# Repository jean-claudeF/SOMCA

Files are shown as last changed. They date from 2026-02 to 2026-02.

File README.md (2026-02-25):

# SOMCA
Switch Off load &amp; Measure Capacity of batteries

Controlled battery discharge and capacity measurement

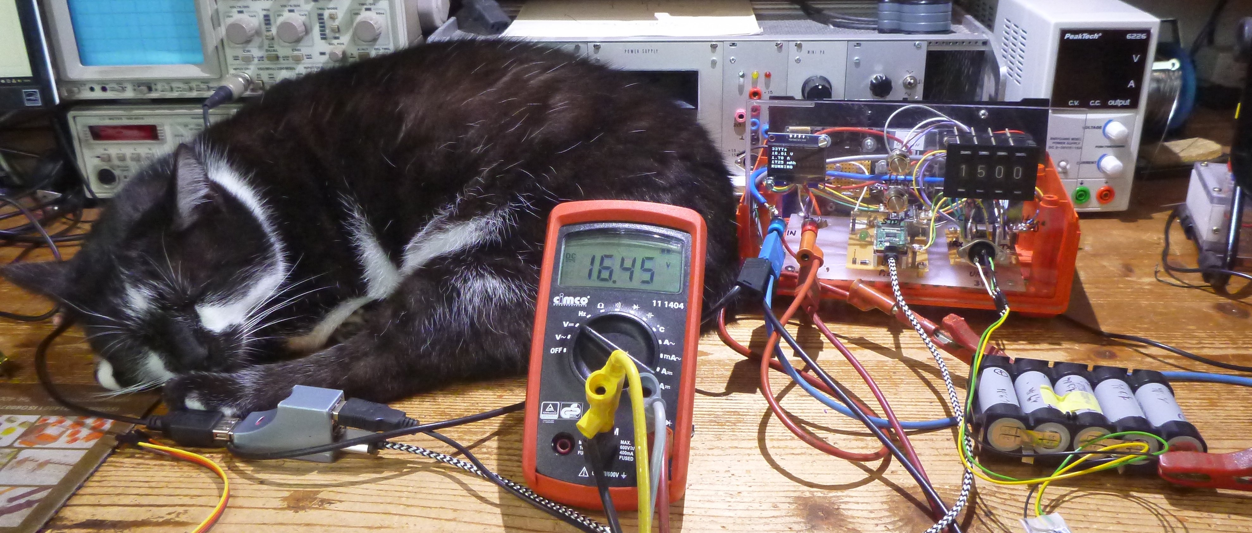
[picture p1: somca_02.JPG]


This picture shows (from left to right) my assistant Billy, a voltmeter showing battery voltage, SOMCA the device that switches off the load when voltage drops below a threshold adjustable with the BCD switches on the right of the frontplate. The battery on the right in front is connected to the input, a power resistor load is lying on the floor and is not visible here.

SOMCA has the following purposes:

1. switch off the load when voltage drops under the threshold, to prevent battery damage
2. measure voltage and current over time
3. from these calculate charge in As and Ah, and energy in Wh
4. store these values for later analysis

In contrast to my other project https://github.com/jean-claudeF/LiIonCapacityMeter that does about the same for single 18650 cells, this is for use with "bigger" batteries like those for electric bicycles or modules from electric cars, like those that I use in my solar energy project.

Limitations:
- voltage must be >= ca. 4V, otherwise the MOSFET will not correctly switch on
- currents up to 10A should be no problem, I have not tested with more

## Hardware

### Switching unit

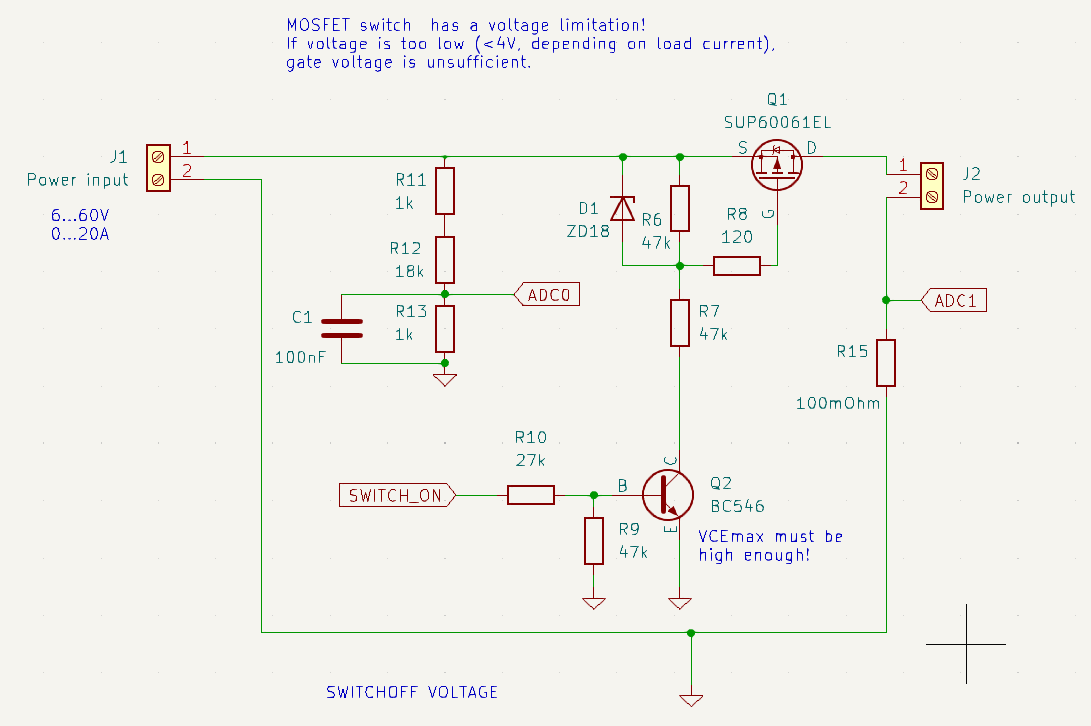
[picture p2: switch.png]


The switching is done by Q1, a low resistance PMOS transistor.

D1 is a zener diode preventing excessive gate voltages.

Q2 must have a high enough VCEmax, the BC546 it is OK for up to 60V. 

There is a voltage divider providing ADC0 signal, and a shunt R15 providing the ADC1 signal for measuring the current.

### BCD switches and port expander

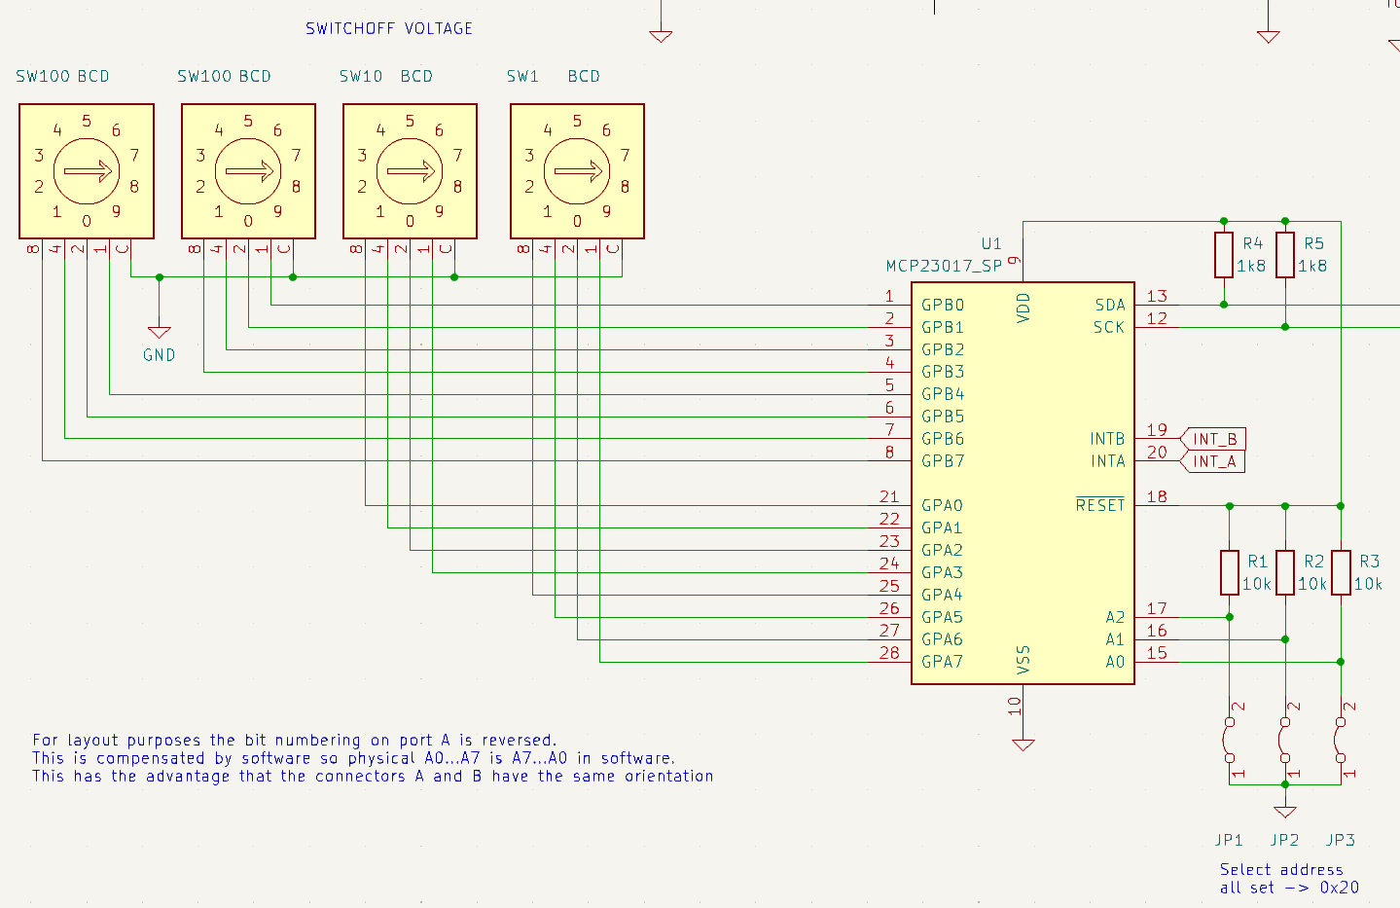
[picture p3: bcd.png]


I used these nice BCD switches because they were laying around and I thought they would be happy to serve in a real application. Another motivation was that I had used the MCP23017 port expander recently and I liked it very much.
The port expander is connected to the I2C bus and so only needs 2 Pico pins.

### Display and ADC

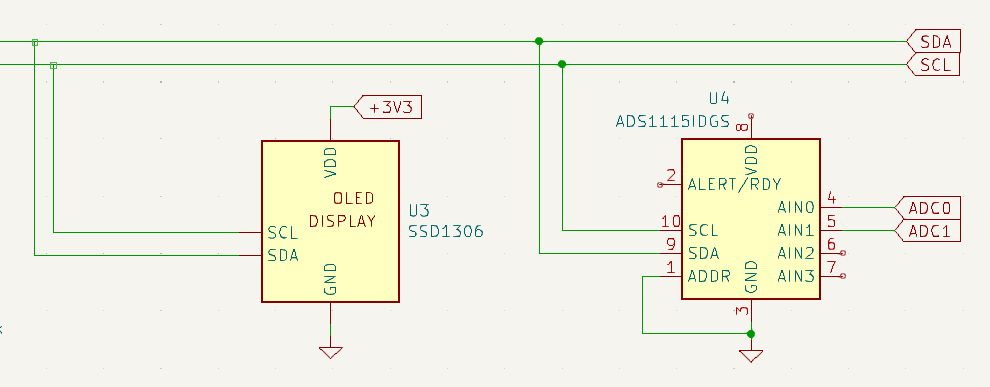
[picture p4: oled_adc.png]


The display is an 1.3" OLED SH1106. It displays:

- time in seconds
- voltage
- current
- charge in mAh
- Status

The ADC is an ADS1115 with only 2 channels used for the moment. I had first used the internal Pico ADC, but I was not happy with the resolution. The ADS1115 does a better job.

### Pico and the rest

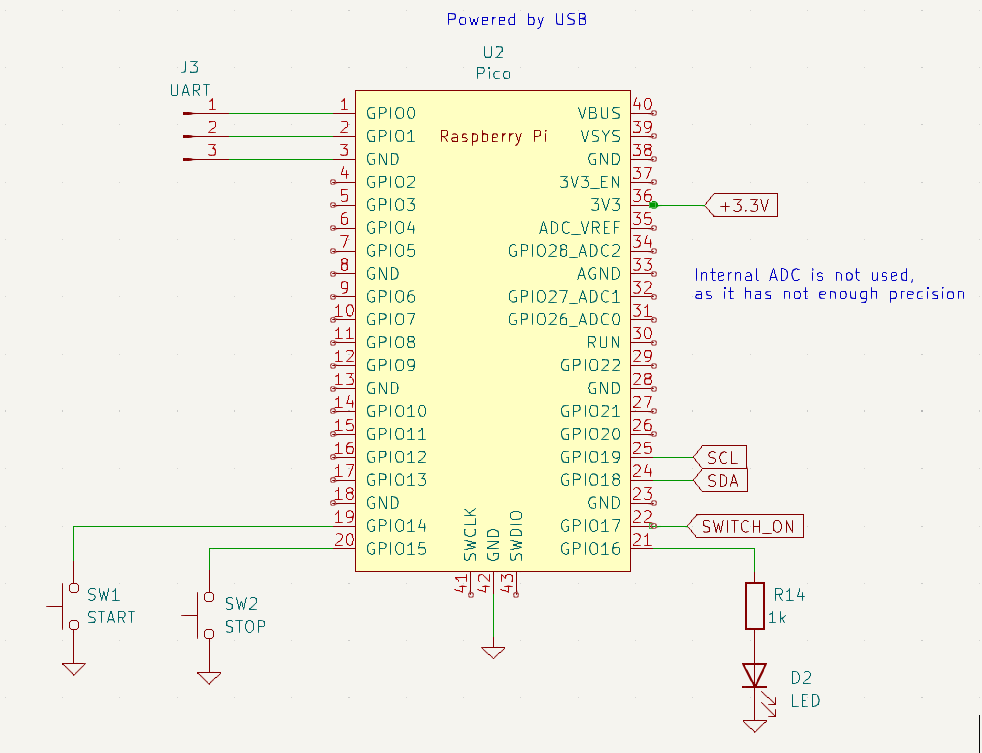
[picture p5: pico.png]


There are 2 buttons: START and STOP.

The STOP button also has the function to transmit recorded values if needed.

A LED blinks every second while discharging.

## Micropython software

The somca_xx file is imported by main.py

There is a folder test that contains test programs for all hardware elements. This concept is really useful for debugging.

A file info.txt contains a keyword that is used for communication with the PC software.

## Python software 

For simplicity there is a command line interface. If you want, you can easily make a Tkinter interface instead.

The connection with the Pico is done with the module picoconnect_pa02. This automatically finds the right Pico with the keyword "SOMCA" in the file info.txt, and connects.
Then it reads the file values.dat, calculates the stored charge in Ah and energy in Wh, and plots several interesting diagrams.

I added an option to read stored data files.

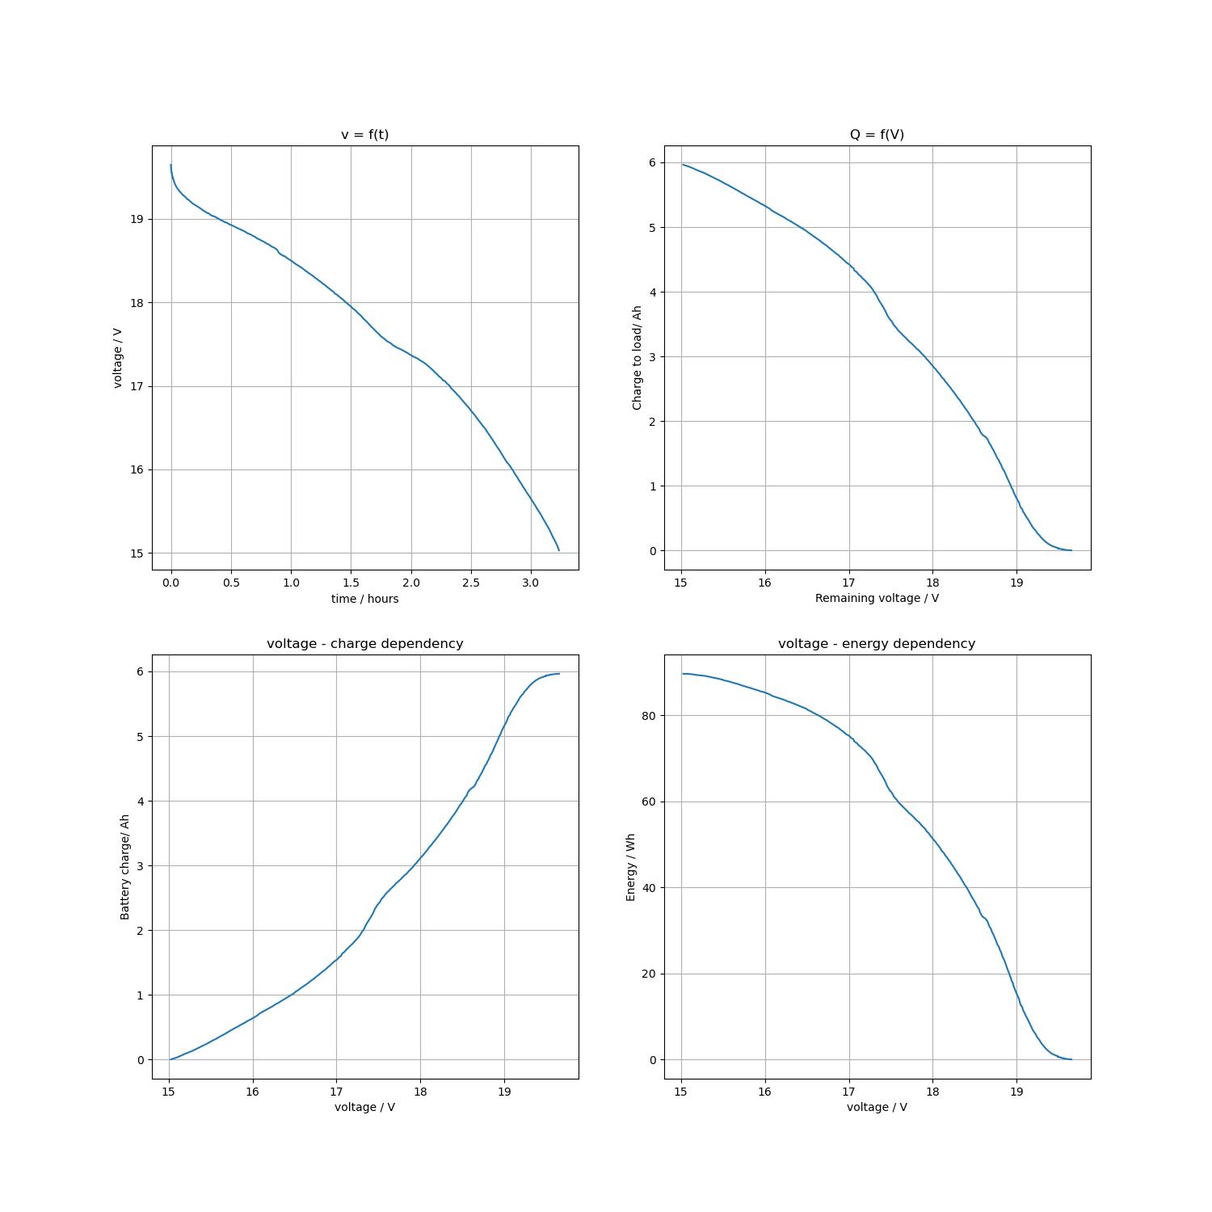
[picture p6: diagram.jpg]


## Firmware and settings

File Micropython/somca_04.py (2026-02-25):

# SOMCA 04
# Switch off load and measure capacity

# Intervals in seconds for storing data in internal filesystem:
store_interval1 = 2       # beginning
store_interval2 = 60      # when longer than 1 minute
store_interval = 1        # initial value

current_min = 0.03        # current smaller than this is set to zero to avoid summing over nearly nothing thus causing errors in Q and W

filename = 'values.dat'
header = '# t/s \t U/V \t I/A \t Q/As \t Q/mAh \t P/W \t W/mWh\n'



from oled_07 import create_oled_class, set_oled_type
from machine import Pin, ADC, Timer, I2C, PWM, UART
import time
import os, sys

from adc_ADS1115_04 import ADS1115
from mcp23017_01 import MCP23017

# Interrupt timer:
timer = Timer()

#-----------------------------------------------------
# Hardware related:
# Buttons and LED = switch on / off:
btn_start = Pin(14, Pin.IN, Pin.PULL_UP)
btn_stop = Pin(15, Pin.IN, Pin.PULL_UP)
led = Pin(16, Pin.OUT)
gate = Pin(17, Pin.OUT)

# I2C: OLED and ADC
i2c = I2C(1, scl=Pin(19), sda=Pin(18))
set_oled_type("SH1106")
OLED = create_oled_class()
oled = OLED(128, 64, i2c, rotate = 180)
oled.clear()

adc = ADS1115(i2c, address = 72, gain = 1)

# voltage lin. transform:
adc.factors[0] = 20  #* 1.035298
adc.offsets[0] = 0.0006

# current lin. transform:
adc.factors[1] = 10
adc.offsets[1] = 0.002

# Threshold voltage via BCD switches and port expander:
mcp = MCP23017(i2c)
mcp.reverse_A = True     # this gives the same bit sequence as for B (with A0 on pin 20)
mcp.init_BCD4()
##mcp.print_regs()

# extra UART (non USB):
uart = UART(0, baudrate = 9600)

"""
# DAC via PWM for current setting (if needed later):
pwm = PWM(Pin(3))
pwm.duty_u16(32767)
pwm.freq(100000)

def set_dac(v):
    duty = int(65535 * v / 3.3)
    pwm.duty_u16(duty)
"""

#--------------------------------------------------------------------
seconds = 0
voltage = 0
current = 0
nbval = 0

Q_As = 0
Q_mAh = 0
power = 0
energy_mWh = 0


#------------------------------------------------------
def get_threshold():
    # Read threshold value from BCD switches
    c = mcp.read_BCD4()
    return float(c)/100

#----------------------------------------------------

def say_hello():
    print("ACCU DISCHARGE")
    print("# I2C Address      : "+hex(i2c.scan()[0]).upper()) # Display device address
    print("# I2C Configuration: "+str(i2c))                   # Display I2C config
    print("# Waiting for start button")
    
    time.sleep(1)


def print_values():
    s = "%i\t%.3f\t%.3f\t%.3f\t%.3f" % (seconds, voltage, current, Q_As, Q_mAh)
    print(s)
    uart.write(s + '\n\r')
    
    
def oled_waiting():
    oled.fill(0)
    #oled.text("%.3f V" % voltage, 0, 12)
    oled.text("WAIT for START",0,2)
    oled.text16("%.3f V" % voltage, 0, 20)
    oled.text("STOP = Send data", 0, 50)
    oled.show()

def oled_running():
    oled.fill(0)
    oled.text(str(seconds) +"s", 0, 0)
    oled.text("%.2f V" % voltage, 0, 12)
    oled.text("%.2f A" % current, 0, 24)
    oled.text("%i mAh" % Q_mAh, 0, 36)
    oled.text("RUNNING", 0, 48)
    oled.show()
    
def oled_stopped():
    oled.fill(0)
    oled.text(str(seconds) + "s", 0, 0)
    oled.text("%.2f V" % voltage, 0, 12)
    oled.text("%.2f A" % current, 0, 24)
    oled.text("%i mAh" % Q_mAh, 0, 36)
    oled.text("STOPPED", 0, 48)
    oled.show()

def oled_sentdata(l):
    oled.fill(0)
    oled.text("SENT DATA", 0, 12)
    oled.text(str(l) + " chars", 0, 24)
    oled.text("RESET TO START", 0, 48)
    oled.show()

def oled_error(e):
    oled.fill(0)
    oled.text("ERROR !", 0, 12)
    oled.text(e, 0, 24)
    oled.text("RESET TO START", 0, 48)
    oled.show()

"""
def set_current(I):
    # (if needed later)
    set_dac(I)
"""

#--------------------------------------------------------

def set_current(onoff):
    # for now, switch load on or off
    gate.value(onoff)


    
def measure():
    # measure and read threshold
    global voltage, current, threshold, Q_As, Q_mAh
    
    values = adc.read_all_meanvalue(rate = 4, nb = 10)
    voltage = values[0]
    current = values[1]
    if current < current_min:
        current = 0
    threshold = get_threshold()
    
    
    
#-------------------------------------------------------------
import gc
def print_free_memory():
    free_memory = gc.mem_free()
    print("Free memory: {} bytes".format(free_memory))
    
#------------------------------------------------------------------------
def delete_old_file():
    try:
        os.remove(filename)
        print("# Remove old " + filename)
    except:
        print("# Could not delete " + filename)
        print(os.listdir())


def create_file():
    try:
        f = open(filename, 'w')
        f.write('# Measure capacity\n')
        f.write("# V0 = %.3fV\n" % idle_voltage)
        f.write(header)       
        f.close()
    except:
        print("Error creating " + filename)

    
def store():
    s = "%i\t%.3f\t%.2f\t%.2f\t%.3f\t%.2f\t%.0f" % (seconds, voltage, current, Q_As, Q_mAh, power, energy_mWh)
    f = open(filename, "a") 
    f.write(s + '\n')
    f.close()    

def store_footer():
    f = open(filename, "a")
    f.write("# STOPPED at %.3fV\r\n" % voltage)
    f.write("# Q = %.2fmAh\r\n" % Q_mAh)
    f.write("# W = %.0fmWh\r\n" % energy_mWh)
    f.close()

def send_data():
    # Read data from internal filesystem file and transmit them via USB and UART
    # ( Not really needed if software on PC is used)
    led.on()
    ##time.sleep(1)
    print()
    try:
        f = open(filename, 'r')
        t = f.read()
        f.close()
        print(t)
        print()
        
        uart.write('\n\r\n')
        for l in t.splitlines():
            uart.write(l + '\r\n')
            time.sleep(0.01)
        uart.write('\n\r\n')
        oled_sentdata(len(t))
    except:
        print("Could not read " + filename)
        oled_error("Error sending data")
    ##time.sleep(1)
    led.off()
    
#----------------------------------------------------------

# These are the main loops:
    
def waiting_loop():
    # Wait for button start
    global idle_voltage
    while btn_start.value():
        if btn_stop.value() == 0:
            send_data()
            #sys.exit()
        measure()
        print("##   %.3fV" % voltage, end = '\r')
        #uart.write("##   %.3fV\r" % voltage)
        idle_voltage = voltage
        oled_waiting()
        time.sleep(0.05)
        
        if btn_start.value() == 0:
            gate.on()
            print("## ON")
            time.sleep(0.03)
            return

def measuring_loop():
    # Once the start button is pushed, measure in a loop
    # until either STOP button is pushed or voltage goes below threshold
    # Store values, in short intervals at the beginning and longer intervals
    # later, to avoid filesystem overflow
    
    global seconds, voltage, current, threshold, Q_As, Q_mAh, power, energy_mWh
    
    time0 = time.time()        # start time of loop
    time1 = time0              # effective cycle time
    time_store = time0
    
    measure()
    
    
    Q_As = 0
    Q_mAh = 0
    energy_mWh = 0
    energy_Ws = 0
    
    i = 0
    while True:
        
        # print header every 10 lines:
        if i % 10 == 0:
            print(header)
            uart.write(header + '\r\n')
            i+=1
        
        # Stop if STOP btn or < threshold:    
        if btn_stop.value() == 0  or voltage < threshold:
            gate.off()
            print("## OFF")
            time.sleep(0.03)
            return
        
        # every second:
        if time.time()-time1 >= 1:
            time1 = time.time()
            seconds = time.time()-time0
                        
            led.on()
            measure()
            power = voltage * current
            Q_As += current
            Q_mAh = Q_As / 3.6
            energy_Ws +=  power
            energy_mWh = energy_Ws / 3.6
            
            s = s = "%i\t%.3f\t%.3f\t%.2f\t%.2f\t%.1f\t%.0f" % (seconds, voltage, current, Q_As, Q_mAh, power, energy_mWh)
            print(s)
            uart.write(s + '\r\n')
            oled_running()
            led.off()
            
            
        
        
            # store every store_interval
            if seconds <= 60:
                store_interval = store_interval1
            else:
                store_interval = store_interval2
            
            if time.time()-time_store >= store_interval:
                time_store = time.time()
                print("# Storing")
                store()
        
        time.sleep(0.01)
        
def print_footer():
    # Print important data at the bottom
    
    print("# STOPPED at %.3fV" % voltage)
    print("# Q = %.2fmAh" % Q_mAh)
    print("# W = %.0fmWh" % energy_mWh)
    
    uart.write("# STOPPED at %.3fV\r\n" % voltage)
    uart.write("# Q = %.2fmAh\r\n" % Q_mAh)
    uart.write("# W = %.0fmWh\r\n" % energy_mWh)


    
#--------------------------------------------------------------------------------------
##   MAIN
threshold = get_threshold()

print_free_memory()

while True:

    set_current(0)
    say_hello()
    
    waiting_loop()
    
    # Prepare things:
    print("\n # Start")
    print(header)
    delete_old_file()
    measure()
    create_file()
    
    # Switch on and measure until stopped
    # by button or undervoltage:
    set_current(1)
    store()
    measuring_loop()
        
    # When stopped:    
    set_current(0)
    print_footer()
    store_footer()
    oled_stopped()
    
    time.sleep(1)
    
    # Restart? Wait for start button
    print("RESTART -> START")
    time.sleep(1)
    
    while btn_start.value():
        time.sleep(0.05)
        

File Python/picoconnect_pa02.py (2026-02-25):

'''Module for connecting to named Picos

by jean-claude.feltes@education.lu

The name (or keyword) must be the first line of a file info.txt on the Pico

# Usage:

from picoconnect_pa01 import create_pico_dictionary, Pico, CMD_TEST

create_pico_dictionary()

keyword = "SWISS"
mypico = Pico(keyword)
mypico.connect()
mypico.execute(CMD_TEST)
mypico.execute("x = 5; print (2* 3.14 * x)")
mypico.list_files()
mypico.read_file("main.py")
mypico.close()

# First create a dictionary of Picos before calling other functions!
(If you don't, it is created automatically at first definition of Pico(keyword).
Why is it better to do this at the beginning? 
Because to read the info file the running program on the pico must be
stopped, and this can be a problem when using more than one Pico.
Don't bother, if you use create_pico_dictionary() at the beginning,
everything is fine

Example see main section
'''

import serial
import time
from serial.tools import list_ports

RESPONSE_TIMEOUT = 5        # This could be chosen greater 
                            # in case of problems

#-----------------------------------------------------------------------
# Do not edit this!

CMD_GETINFO ="""
try:
    f = open("info.txt", "r")
    t = f.readline()
    f.close()
except:
    t = ""
print("KEY=",t,"=ENDKEY")
"""

CMD_LISTFILES = """import os
files = os.listdir()
for f in files:
    print(f)
"""

CMD_TEST = """x = 56
y = 123
print("Hello from Pico")
print(x+y)
for i in range(0,10):
    print(i ** 2)
print("Good bye from Pico")   
"""

CMD_READFILE1 ="""
try:
    f = open('"""
CMD_READFILE2 = """', "r")
    t = f.read()
    f.close()
except:
    t = ""
print(t)
""" 


CMD_WRITEFILE1 ="""
try:
    f = open('"""
CMD_WRITEFILE2 = """', "w")
    f.write('''"""
CMD_WRITEFILE3 ="""''')
    f.close()
    print("OK")
except:
    print("FILE ERROR")
""" 

PICO_DICTIONARY = {}

#-----------------------------------------------------------------------

# High level functions:

def create_pico_dictionary():
    # returns dictionary in the form {keyword1:port1, keyword2:port2....}  
    # This should be called only once at the beginning 
    # as it stops running programs to access the info file
    global PICO_DICTIONARY
    dict = {}
    for port in scan_for_picoports():
        info = get_info_pico(port)
        dict[info] = port
        PICO_DICTIONARY[info] = port
        
    return dict


def find_pico(keyword):
    '''returns name of the port where a Pico with the right keyword is connected'''
    # if dictionary is not yet created, create it now
    if PICO_DICTIONARY == {}:
        create_pico_dictionary()
    port = PICO_DICTIONARY[keyword]       
    return port


def scan_for_picoports(verbose = True):
    '''returns list of USB portnames with Raspi Picos connected '''
        
    picoports = []
    for port in list_ports.comports():
        if port.manufacturer != None:
            if "MicroPython" in port.manufacturer:
                picoports.append(port.device)
    if verbose:
        print("Pico found on port:")
        for p in picoports:
            print(p) 
        print()               
    return picoports

def scan_picoinfo():
    # returns list of tuples (port, info)
    # if dictionary is not yet created, create it now
    if PICO_DICTIONARY == {}:
        create_pico_dictionary()
    
    picoinfo = []
    for key in PICO_DICTIONARY.keys():
        info = key
        port = PICO_DICTIONARY[key] 
        picoinfo.append([port,info])
    """
    for port in scan_for_picoports():
        info = get_info_pico(port)
        print(port, ":   ", info)
        picoinfo.append([port,info])
    """    
    return picoinfo
    
#---------------------------------------------------------------------    
    
# port related    

def open_picoport(port):
    ser = serial.Serial(port, baudrate=115200)
    if ser.isOpen()==False:
        ser.open()
    flush_input_buffer(ser)
    return ser



def get_info_pico(port):
    # get info on Pico on port port
    ser = open_picoport(port)
    r = pico_get_info(ser)
    ser.close()
    return r

#----------------------------------------------------------------------

# Functions that operate on a Serial object already opened:

def flush_input_buffer(ser):
    n = ser.in_waiting
    ser.read(n) 


def rawREPL(ser):
    # Ctrl - A
    ser.write(b'\x01')     
    
def normalREPL(ser):
    # Ctrl - B
    ser.write(b'\x02') 
    
def interrupt_program(ser):
    # Ctrl - C
    ser.write(b'\x03\x03')
    time.sleep(0.1)
    
    
def soft_reset(ser):
    interrupt_program(ser)
    # Ctrl - D
    ser.write(b'\x04\x04')                          
   
    
def paste_mode(ser):
    # Ctrl - E
    ser.write(b'\x05')  
    
def end_paste_mode(ser):
    # Ctrl - D
    ser.write(b'\x04')        
    
def send_commands(ser,cmds):
    ser.write(cmds.encode("utf8"))
    ser.write(b'\x0D\x0A')

def debug_get_response(ser, timeout = 10):
    # for debugging purposes only, interrupt with Ctrl-C 
    t1 = time.time()
    while True:
        if ser.inWaiting():
            c = ser.read()
            try:
                cc = c.decode("utf-8")
            except:
                cc = "_DECODE ERROR_"    
            print(cc, end = "")
        if time.time() - t1 > timeout:
            print("TIMEOUT!")
            break    

def get_response(ser, timeout = RESPONSE_TIMEOUT):
    # get everything that is printed from the Pico (in paste mode)
    t1 = time.time()
    response = ""
    while True:
        
        # add to response
        if ser.inWaiting():
            c = ser.read()
            try:
                cc = c.decode("utf-8")
            except:
                cc = "_DECODE ERROR_"    
            
            response += cc
        
        # check for end of paste mode:
        if ">>>" in response[10:]:
            # at the end, not at the beginning: return to normal REPL,
            response= response[:-3]     # cut off ">>>"
            break
                
        # break if timeout
        if time.time() - t1 > timeout:
            print("TIMEOUT!")
            break    
    
    # cut off beginning 
    p1 = response.find("===")   # begin paste mode
    p2 = response.find("===", p1 + 1)
    response = response[p2+3+4:]
    return response

def pico_execute(ser, cmds, debug = False):
    # execute commands in paste mode and return response
    # response = everything that is printed from Pico
    flush_input_buffer(ser)
    paste_mode(ser)
    #time.sleep(0.1)
    send_commands(ser, cmds)
    end_paste_mode(ser)
    normalREPL(ser)
    time.sleep(0.1)
    if debug == False:
        r = get_response(ser)
    else:
        r = debug_get_response(ser)    
    return r
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
